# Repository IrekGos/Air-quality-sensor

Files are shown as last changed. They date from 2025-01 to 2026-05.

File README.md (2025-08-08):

# Air-quality-sensor

Simple IoT system that measures air quality. Based on the ESP32-S3, written in Arduino. Connected to the ThingSpeak cloud.

## Hardware

- XIAO ESP32-S3
- Grove - Laser PM2.5 Sensor (HM3301)
- MCP9700A analog temperature sensor
- IRL540N MOSFET

## Default pinout

| ESP32-S3 | HM3301 |
| --- | --- |
| GPIO 5 | SDA |
| GPIO 6 | SCL |

| ESP32-S3 | MOSFET |
| --- | --- |
| GPIO 44  | Gate |

## Setup

- prepare `credentials.h` file and fill it with your credentials:

```c
#ifndef credentials_h
#define credentials_h

#define SSID "ssid"
#define PASSWORD "password"
#define API_KEY "api_key"

// Identity: DigiCert Global Root G2
// Verified by: DigiCert Global Root G2
// Expires: 15/01/38
#define THINGSPEAK_CERTIFICATE "-----BEGIN CERTIFICATE-----\n\
MIIDjjCCAnagAwIBAgIQAzrx5qcRqaC7KGSxHQn65TANBgkqhkiG9w0BAQsFADBh\n\
MQswCQYDVQQGEwJVUzEVMBMGA1UEChMMRGlnaUNlcnQgSW5jMRkwFwYDVQQLExB3\n\
d3cuZGlnaWNlcnQuY29tMSAwHgYDVQQDExdEaWdpQ2VydCBHbG9iYWwgUm9vdCBH\n\
MjAeFw0xMzA4MDExMjAwMDBaFw0zODAxMTUxMjAwMDBaMGExCzAJBgNVBAYTAlVT\n\
MRUwEwYDVQQKEwxEaWdpQ2VydCBJbmMxGTAXBgNVBAsTEHd3dy5kaWdpY2VydC5j\n\
b20xIDAeBgNVBAMTF0RpZ2lDZXJ0IEdsb2JhbCBSb290IEcyMIIBIjANBgkqhkiG\n\
9w0BAQEFAAOCAQ8AMIIBCgKCAQEAuzfNNNx7a8myaJCtSnX/RrohCgiN9RlUyfuI\n\
2/Ou8jqJkTx65qsGGmvPrC3oXgkkRLpimn7Wo6h+4FR1IAWsULecYxpsMNzaHxmx\n\
1x7e/dfgy5SDN67sH0NO3Xss0r0upS/kqbitOtSZpLYl6ZtrAGCSYP9PIUkY92eQ\n\
q2EGnI/yuum06ZIya7XzV+hdG82MHauVBJVJ8zUtluNJbd134/tJS7SsVQepj5Wz\n\
tCO7TG1F8PapspUwtP1MVYwnSlcUfIKdzXOS0xZKBgyMUNGPHgm+F6HmIcr9g+UQ\n\
vIOlCsRnKPZzFBQ9RnbDhxSJITRNrw9FDKZJobq7nMWxM4MphQIDAQABo0IwQDAP\n\
BgNVHRMBAf8EBTADAQH/MA4GA1UdDwEB/wQEAwIBhjAdBgNVHQ4EFgQUTiJUIBiV\n\
5uNu5g/6+rkS7QYXjzkwDQYJKoZIhvcNAQELBQADggEBAGBnKJRvDkhj6zHd6mcY\n\
1Yl9PMWLSn/pvtsrF9+wX3N3KjITOYFnQoQj8kVnNeyIv/iPsGEMNKSuIEyExtv4\n\
NeF22d+mQrvHRAiGfzZ0JFrabA0UWTW98kndth/Jsw1HKj2ZL7tcu7XUIOGZX1NG\n\
Fdtom/DzMNU+MeKNhJ7jitralj41E6Vf8PlwUHBHQRFXGU7Aj64GxJUTFy8bJZ91\n\
8rGOmaFvE7FBcf6IKshPECBV1/MUReXgRPTqh5Uykw7+U0b6LJ3/iyK5S9kJRaTe\n\
pLiaWN0bfVKfjllDiIGknibVb63dDcY3fe0Dkhvld1927jyNxF1WW6LZZm6zNTfl\n\
MrY=\n\
-----END CERTIFICATE-----"

#endif
```

- open Arduino IDE and install `ArduinoJson` library
- add ESP32 board package to your Arduino IDE (instruction [here](https://wiki.seeedstudio.com/xiao_esp32s3_getting_started/#software-preparation))
- build code and upload to your board

## Air Quality Index

Polish scale provided by the Chief Inspectorate of Environmental Protection ([source](https://powietrze.gios.gov.pl/pjp/content/health_informations)).

| AQI | PM2.5 [µg/m3 ] | PM10 [µg/m3 ] |
| --- | --- | --- |
| Very good | 0 - 13 | 0 - 20 |
| Good | 13.1 - 35 | 20.1 - 50 |
| Moderate  | 35.1 - 55 | 50.1 - 80 |
| Fair | 55.1 - 75 | 80.1 - 110 |
| Poor | 75.1 - 110 | 110.1 - 150 |
| Very poor | > 110 | > 150 |

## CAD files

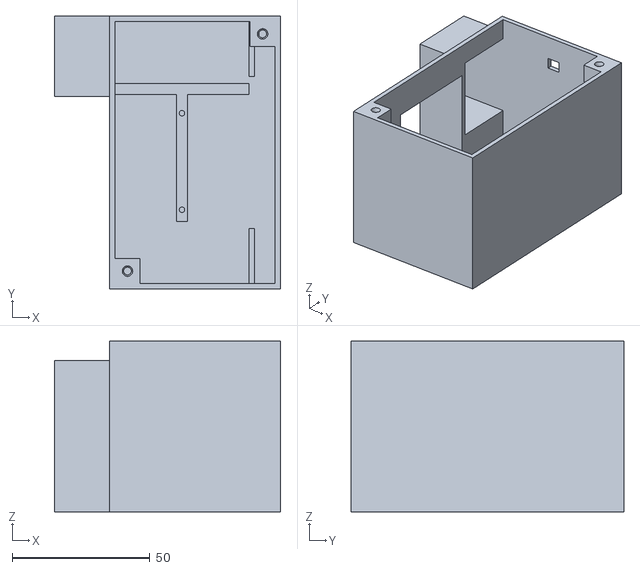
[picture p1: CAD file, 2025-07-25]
3D model - housing/air_quality_sensor-housing.stl
82.0 x 99.0 x 62.0

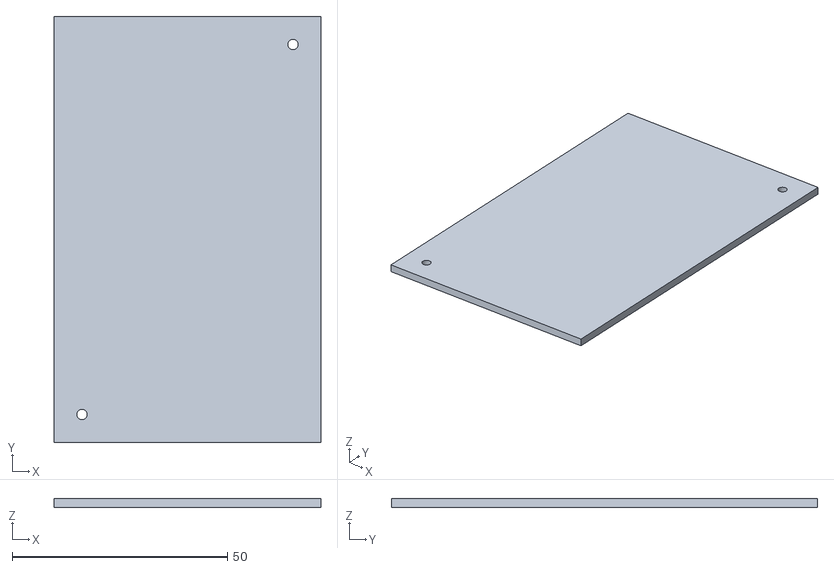
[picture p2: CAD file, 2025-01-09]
3D model - housing/air_quality_sensor-lid.stl
62.0 x 99.0 x 2.00

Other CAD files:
3D model - housing/air_quality_sensor.FCStd

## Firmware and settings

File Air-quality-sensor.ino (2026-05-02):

#include <HTTPClient.h>
#include <ArduinoJson.h>
#include <WiFi.h>
#include <esp_system.h>
#include "measurements.h"
#include "dust_sensor.h"
#include "wifi.h"
#include "credentials.h"

#define DEBUG_MODE false

#define NUMBER_OF_ATTEMPTS 10
#define uS_TO_S_FACTOR 1000000

// 64 s - average time spent on measurement and sending data
const uint64_t TIME_TO_SLEEP = (uint64_t)uS_TO_S_FACTOR * 60 * 60 - 64;
const char* URL = "https://api.thingspeak.com/update.json";

HTTPClient https;
Measurements measurements;
DustSensor dustsensor;
Wifi wifi;

void signal_start() {
  pinMode(LED_BUILTIN, OUTPUT);
  digitalWrite(LED_BUILTIN, LOW);
  delay(1000);
  digitalWrite(LED_BUILTIN, HIGH);
}

bool send_data(JsonDocument data) {
  data["api_key"] = API_KEY;
  String requestBody;
  serializeJson(data, requestBody);
  int httpsResponseCode = https.POST(requestBody);
  if (DEBUG_MODE)
    Serial.printf("HTTP Response Code: %d\n", httpsResponseCode);
  return httpsResponseCode == HTTP_CODE_OK;
}

void setup() {
  signal_start();
  if (DEBUG_MODE) {
    Serial.begin(115200);
    Serial.setDebugOutput(true);
    delay(100);
    Serial.println("Started");
  }

  if (!https.begin(URL, THINGSPEAK_CERTIFICATE)) {
    esp_restart();
  }
  https.addHeader("Content-Type", "application/json");

  measurements.configure();
  dustsensor.dust_sensor_init();
}

void deep_sleep(uint64_t time) {
  esp_sleep_enable_timer_wakeup(time);
  esp_deep_sleep_start();
}

void loop() {
  JsonDocument dust_results, results;

  uint8_t successful_readings = dustsensor.measure_air_quality(dust_results);
  results["field7"] = successful_readings;

  if (successful_readings) {
    results["field1"] = dust_results["PM1"];
    results["field2"] = dust_results["PM2.5"];
    results["field3"] = dust_results["PM10"];
  }

  float internal_temp = measurements.measure_internal_temp();
  float ambient_temp = measurements.measure_ambient_temp();
  float supply_voltage = measurements.measure_supply_voltage();

  results["field4"] = ambient_temp;
  results["field5"] = internal_temp;
  results["field6"] = supply_voltage;

  if (DEBUG_MODE) {
    delay(500);
    Serial.println("results:");
    serializeJson(results, Serial);
    Serial.println("");
    Serial.flush();
  }

  for (uint8_t i = 1; i <= NUMBER_OF_ATTEMPTS; i++) {
    wifi.connect();
    if (DEBUG_MODE)
      Serial.printf("is WiFi connected: %d\n", wifi.is_connected());
    if (wifi.is_connected()) {
      results["field8"] = i;
      if (send_data(results)) {
        wifi.turn_off();
        break;
      }
    }
    wifi.turn_off();
  }

  deep_sleep(TIME_TO_SLEEP);
}

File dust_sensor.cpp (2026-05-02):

// HM3301 dust sensor datasheet:
// https://files.seeedstudio.com/wiki/Grove-Laser_PM2.5_Sensor-HM3301/res/HM-3300%263600_V2.1.pdf

#include <Arduino.h>
#include <ArduinoJson.h>
#include <Wire.h>
#include "dust_sensor.h"

#define I2C_FREQUENCY 100000
#define SENSOR_I2C_ADDRESS 0x40
#define DATA_LENGTH 29
#define NUMBER_OF_ATTEMPTS 10
#define NUMBER_OF_MEASUREMENTS 5
#define uS_TO_S_FACTOR 1000000

const uint64_t TIME_TO_SLEEP = (uint64_t)uS_TO_S_FACTOR * 30;

const uint8_t mosfet_pin = D7;

void DustSensor::dust_sensor_init() {
  Wire.begin();
  Wire.setClock(I2C_FREQUENCY);
  Wire.setTimeOut(200);
  gpio_hold_dis((gpio_num_t)mosfet_pin);
  pinMode(mosfet_pin, OUTPUT);
  digitalWrite(mosfet_pin, LOW);
}

void DustSensor::sleep_mode(bool mode) {
  if (mode) {
    digitalWrite(mosfet_pin, LOW);
  } else {
    digitalWrite(mosfet_pin, HIGH);
  }
}

void DustSensor::reset() {
  sleep_mode(true);
  light_sleep(0.5 * uS_TO_S_FACTOR);
  sleep_mode(false);
}

void DustSensor::light_sleep(uint64_t time) {
  esp_sleep_enable_timer_wakeup(time);
  esp_light_sleep_start();
}

bool DustSensor::read_sensor_value(uint8_t *temp) {
  uint8_t bytesReceived = Wire.requestFrom(SENSOR_I2C_ADDRESS, DATA_LENGTH);
  if (bytesReceived == DATA_LENGTH) {
    Wire.readBytes(temp, bytesReceived);
  }
  return bytesReceived == DATA_LENGTH;
}

void DustSensor::parse_result(uint8_t *raw_bytes, measurement_result *result) {
  // based on datasheet, chapter "Appendix 2: IIC Communication Protocol"
  result->pm1 = (raw_bytes[4] << 8) | raw_bytes[5];
  result->pm2_5 = (raw_bytes[6] << 8) | raw_bytes[7];
  result->pm10 = (raw_bytes[8] << 8) | raw_bytes[9];
}

bool DustSensor::are_values_correct(measurement_result *result) {
  int bad_value = (1 << 16) - 1;
  bool valid_range = result->pm1 != bad_value && result->pm2_5 != bad_value && result->pm10 != bad_value;
  // Reject physically impossible measurements: smaller particles must not exceed larger particles
  bool physically_valid = result->pm1 <= result->pm2_5 && result->pm2_5 <= result->pm10;
  return valid_range && physically_valid;
}

void DustSensor::add_result_to_accumulator(measurement_result *result, measurement_result *accumulator) {
  accumulator->pm1 += result->pm1;
  accumulator->pm2_5 += result->pm2_5;
  accumulator->pm10 += result->pm10;
}

void DustSensor::calc_mean_value(measurement_result *accumulator, uint8_t successful_readings) {
  accumulator->pm1 /= successful_readings;
  accumulator->pm2_5 /= successful_readings;
  accumulator->pm10 /= successful_readings;
}

void DustSensor::store_value(JsonDocument &results, measurement_result *accumulator) {
  results["PM1"] = accumulator->pm1;
  results["PM2.5"] = accumulator->pm2_5;
  results["PM10"] = accumulator->pm10;
}

uint8_t DustSensor::measure_air_quality(JsonDocument &results) {
  // from datasheet, chapter "6. Pin definition":
  // "It takes at least 30 seconds for stabilize when restart the fan."
  sleep_mode(false);
  light_sleep(TIME_TO_SLEEP);
  uint8_t buf[DATA_LENGTH];
  measurement_result tmp, accumulator = { 0 };
  uint8_t successful_readings = 0;
  for (uint8_t i = 0; i < NUMBER_OF_ATTEMPTS; i++) {
    if (read_sensor_value(buf)) {
      parse_result(buf, &tmp);
      if (are_values_correct(&tmp)) {
        successful_readings++;
        add_result_to_accumulator(&tmp, &accumulator);
        if (successful_readings == NUMBER_OF_MEASUREMENTS) {
          break;
        }
      } else {
        reset();
      }
    } else {
      reset();
    }
    light_sleep(1 * uS_TO_S_FACTOR);
  }
  sleep_mode(true);
  // hold mosfet_pin state during deep sleep
  gpio_hold_en((gpio_num_t)mosfet_pin);

  if (successful_readings > 0) {
    calc_mean_value(&accumulator, successful_readings);
    store_value(results, &accumulator);
  }
  return successful_readings;
}

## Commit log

2025-01-09 Add 3D models of the housing
    [air_quality_sensor-housing.stl, air_quality_sensor-lid.stl, air_quality_sensor.FCStd]
2025-03-15 Fix bugs, remove unnecessary libraries
    [Air-quality-sensor.ino, dust_sensor.cpp, measurements.cpp]
2025-07-25 Small fixes
    - display successful_readings even if it is 0
    - adjust TIME_TO_SLEEP
    [Air-quality-sensor.ino]
2025-07-25 Improve 3D housing model
    - move the sensor hole higher for easier assembly
    - add a whole for the USB cable
    [air_quality_sensor-housing.stl, air_quality_sensor.FCStd]
2025-08-08 Change in sensor power supply control
    - the power is controlled by MOSFET
    - reset and sleep pins are no longer used
    [dust_sensor.cpp]
2025-08-08 Add MOSFET to hardware list
